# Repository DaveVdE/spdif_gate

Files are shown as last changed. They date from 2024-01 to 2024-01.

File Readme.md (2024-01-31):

# SPDIF Gate

Forked from [Elehobica's wonderful work](https://github.com/elehobica/pico_spdif_rx) on decoding the S/PDIF protocol on the RP2040's
PIO state machine, I used it to make this small program. I did however break the fork link so that I would not create a PR on the
upstream repo by mistake.

All credit is due to Elehobica's work. Most of the files in this repository come from upstream, I simply added the "spdif_gate" application
in the samples folder.

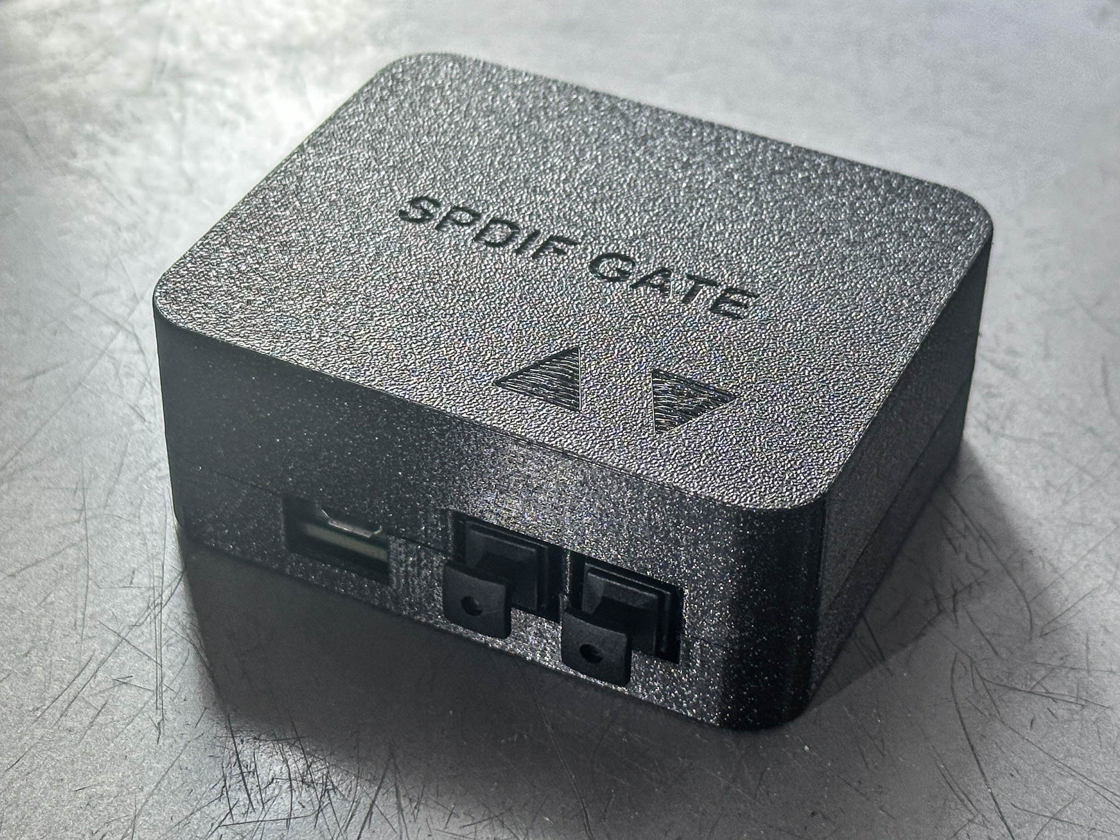
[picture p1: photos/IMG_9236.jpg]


This project started to solve a problem that was created by "Smart TVs" that don't go to sleep when you think they do. They keep humming 
in the background when the display is off, keeping a steady bit stream on their TOSLINK outputs. A family member uses a hairing aid and has 
the problem that a device he uses to convert the TV's optical audio into a bluetooth audio stream doesn't fully turn off when the TV is not 
in use, causing continuous audio cues as he moves around the house upon his hearing aid establishing link with the device near the TV.

I built a device with a custom PCB around a Raspberry Pi Pico, fitted with an optical receiver and transmitter with an AND gate in between 
(technically a quad NAND of which to gates are configured as an AND gate) so that the RP2040 can read the incoming S/PDIF signal and 
decide if real audio is transmitted or if it's just an empty stream with no audio, and turn the gate on and off accordingly 
(with a preset timeout of 3 minutes).

You can find some photos in the photos directory, the schematics and PCB files in the board directory and CAD models for the enclosure in the models directory.

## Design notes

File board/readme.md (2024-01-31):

This folder contains the schematic and PCB files from KiCad

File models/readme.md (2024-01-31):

This folder contains the CAD models used to create the enclosure.

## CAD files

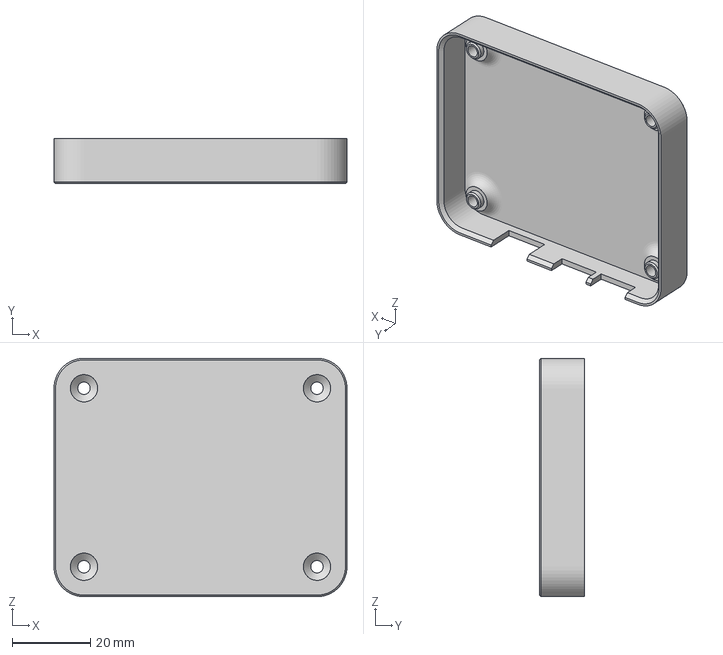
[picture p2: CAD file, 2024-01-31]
models/Bottom.3mf
75.0 x 11.6 x 61.1 mm

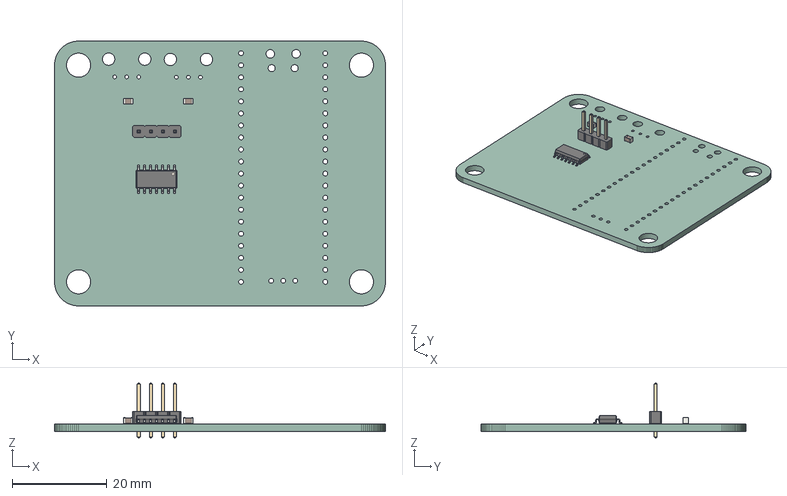
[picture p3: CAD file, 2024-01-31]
models/SPDIF gate.step
69.8 x 55.9 x 11.5 mm
_autosave-SPDIF gate PCB

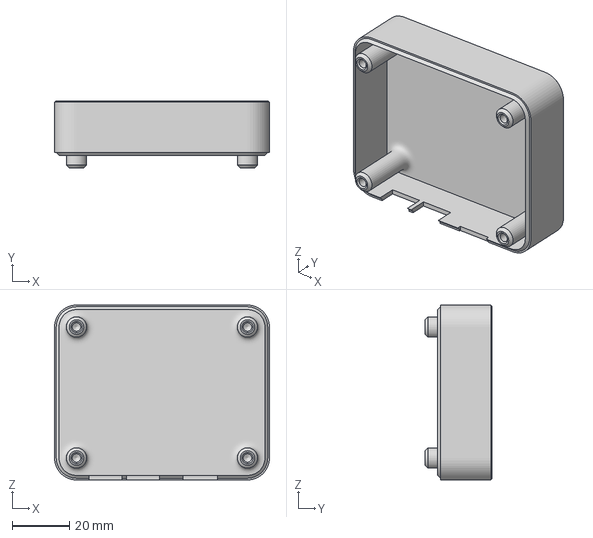
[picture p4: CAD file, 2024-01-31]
models/Top.3mf
75.0 x 23.4 x 61.1 mm

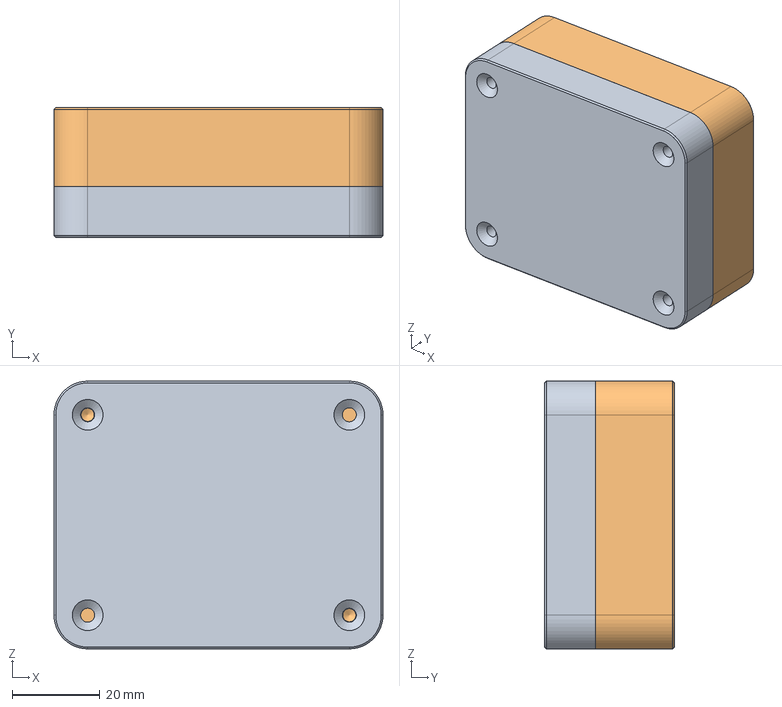
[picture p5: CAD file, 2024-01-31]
models/Enclosure v8.step
75.0 x 29.6 x 61.1 mm

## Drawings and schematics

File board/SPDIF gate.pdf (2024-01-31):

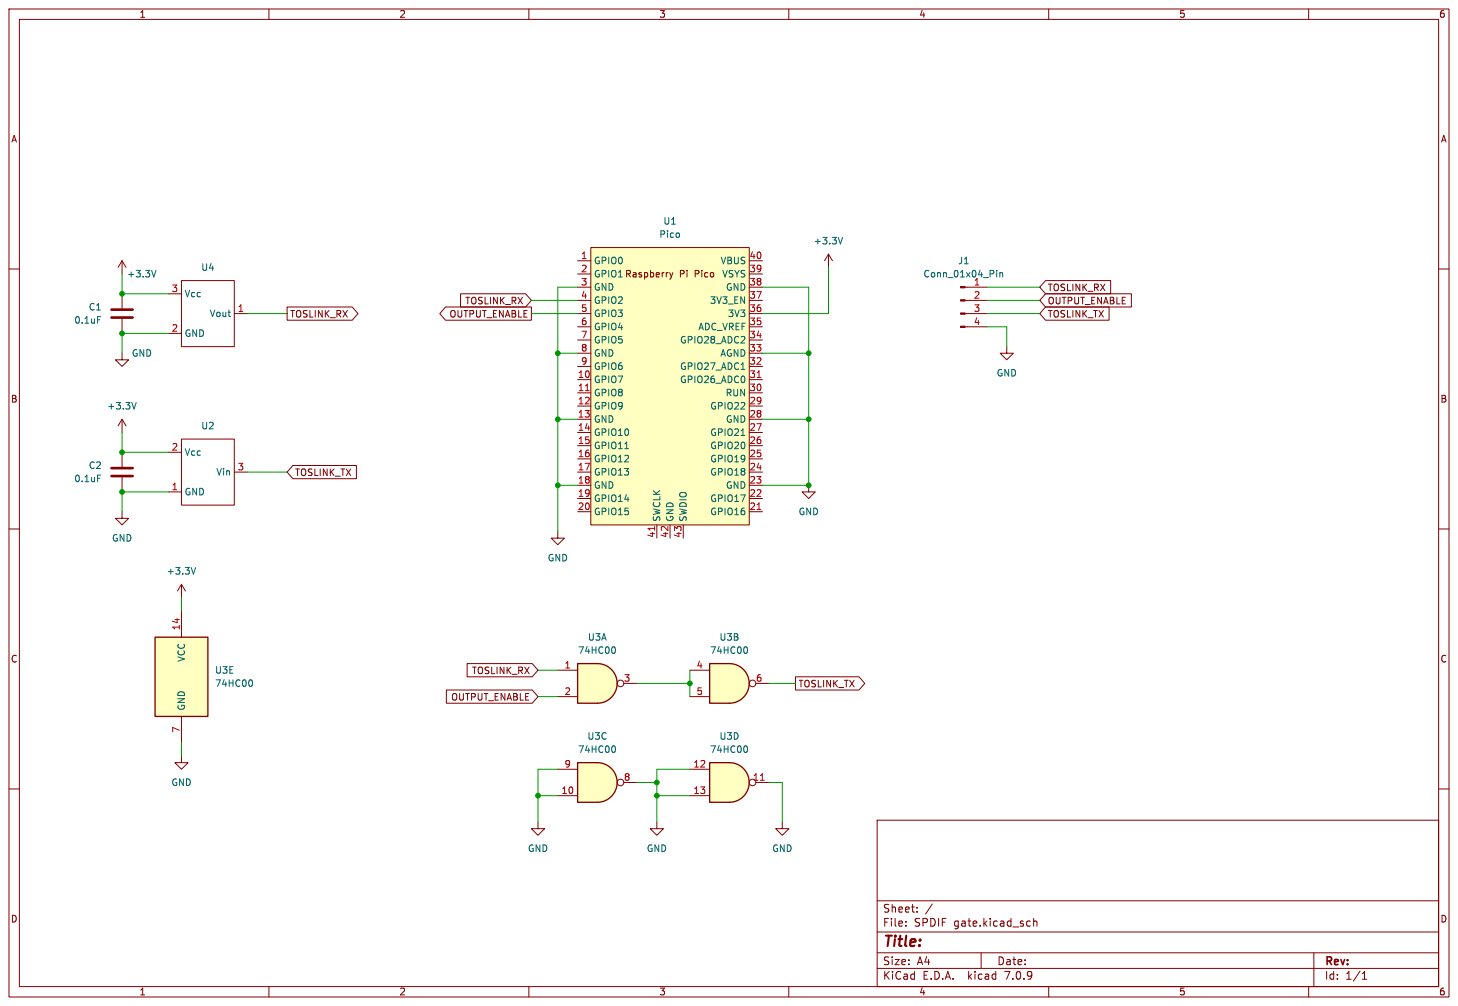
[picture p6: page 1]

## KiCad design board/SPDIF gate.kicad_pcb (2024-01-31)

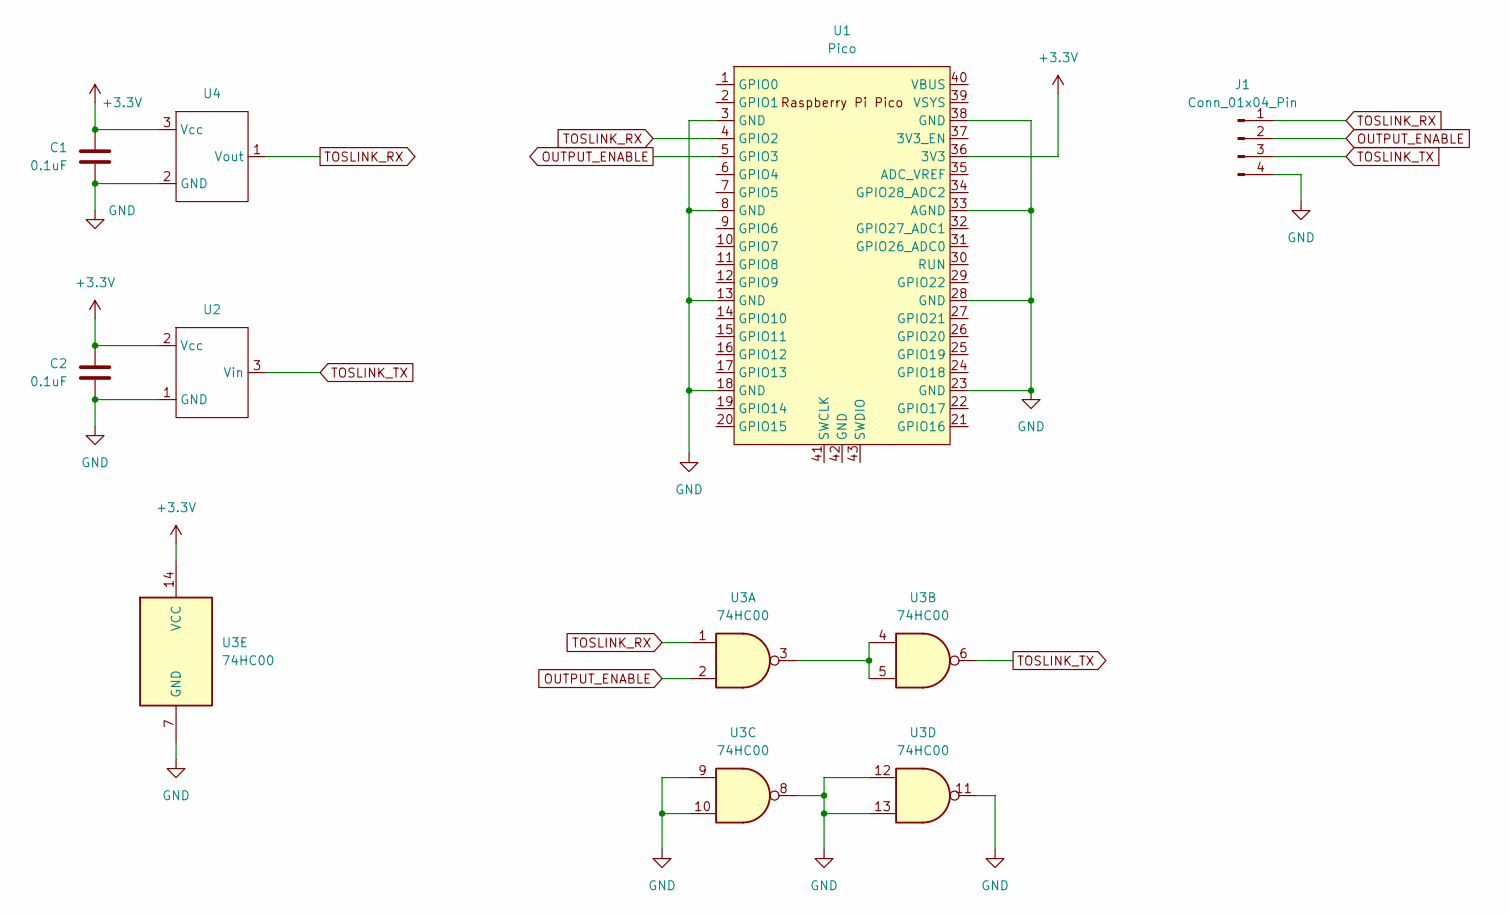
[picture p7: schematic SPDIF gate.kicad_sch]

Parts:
C1, C2: 0.1uF; C_0805_2012Metric
J1: Conn_01x04_Pin; PinHeader_1x04_P2.54mm_Vertical
U1: Pico; RPi_Pico_SMD_TH
U2: OTJ-1
U3: 74HC00; SOIC-14_3.9x8.7mm_P1.27mm
U4: ORJ-1

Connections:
+3.3V: C1.1, C2.1, U1.36 (3V3), U2.2 (Vcc), U3.14 (VCC), U4.3 (Vcc)
GND: C1.2, C2.2, J1.4, U1.3 (GND), U1.8 (GND), U1.13 (GND), U1.18 (GND), U1.23 (GND), U1.28 (GND), U1.33 (AGND), U1.38 (GND), U2.1 (GND), U3.7 (GND), U3.8, U3.9, U3.10, U3.11, U3.12, U3.13, U4.2 (GND)
unnamed: U3.3, U3.4, U3.5
OUTPUT_ENABLE: J1.2, U1.5 (GPIO3), U3.2
TOSLINK_RX: J1.1, U1.4 (GPIO2), U3.1, U4.1 (Vout)
TOSLINK_TX: J1.3, U2.3 (Vin), U3.6

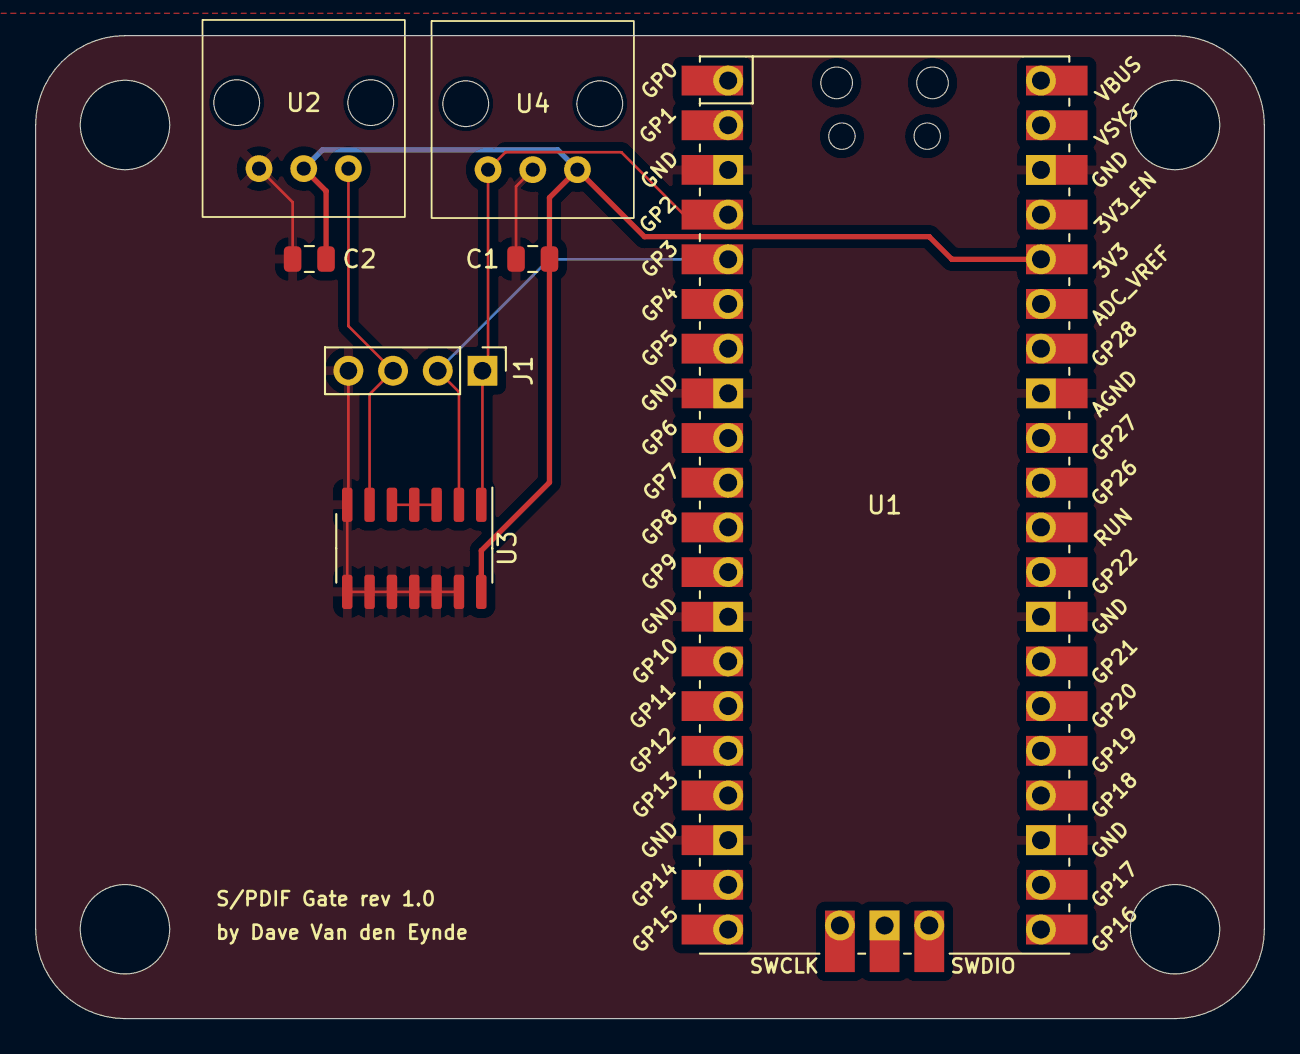
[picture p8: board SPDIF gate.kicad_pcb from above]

Board: 2 copper layers, 69.8 x 55.9 mm, 7 parts (0 on the bottom side), 6 nets.

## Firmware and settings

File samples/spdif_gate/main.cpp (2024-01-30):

/*------------------------------------------------------/
/ Copyright (c) 2023, Elehobica
/ Released under the BSD-2-Clause
/ refer to https://opensource.org/licenses/BSD-2-Clause
/------------------------------------------------------*/

#include <stdio.h>
#include "pico/stdlib.h"
#include "hardware/clocks.h"
#include "spdif_rx.h"

static constexpr uint8_t PIN_DCDC_PSM_CTRL = 23;
static constexpr uint8_t PIN_PICO_SPDIF_RX_DATA = 2;
static constexpr uint8_t PIN_PICO_SPDIF_ENABLE = 3;
static constexpr uint32_t TIMEOUT = 180;

volatile static bool stable_flg = false;
volatile static bool lost_stable_flg = false;

void measure_freqs(void) {
    uint f_pll_sys = frequency_count_khz(CLOCKS_FC0_SRC_VALUE_PLL_SYS_CLKSRC_PRIMARY);
    uint f_pll_usb = frequency_count_khz(CLOCKS_FC0_SRC_VALUE_PLL_USB_CLKSRC_PRIMARY);
    uint f_rosc = frequency_count_khz(CLOCKS_FC0_SRC_VALUE_ROSC_CLKSRC);
    uint f_clk_sys = frequency_count_khz(CLOCKS_FC0_SRC_VALUE_CLK_SYS);
    uint f_clk_peri = frequency_count_khz(CLOCKS_FC0_SRC_VALUE_CLK_PERI);
    uint f_clk_usb = frequency_count_khz(CLOCKS_FC0_SRC_VALUE_CLK_USB);
    uint f_clk_adc = frequency_count_khz(CLOCKS_FC0_SRC_VALUE_CLK_ADC);
    uint f_clk_rtc = frequency_count_khz(CLOCKS_FC0_SRC_VALUE_CLK_RTC);

    printf("pll_sys  = %dkHz\n", f_pll_sys);
    printf("pll_usb  = %dkHz\n", f_pll_usb);
    printf("rosc     = %dkHz\n", f_rosc);
    printf("clk_sys  = %dkHz\n", f_clk_sys);
    printf("clk_peri = %dkHz\n", f_clk_peri);
    printf("clk_usb  = %dkHz\n", f_clk_usb);
    printf("clk_adc  = %dkHz\n", f_clk_adc);
    printf("clk_rtc  = %dkHz\n", f_clk_rtc);

    // Can't measure clk_ref / xosc as it is the ref
}

void on_stable_func(spdif_rx_samp_freq_t samp_freq)
{
    // callback function should be returned as quick as possible
    stable_flg = true;
}

void on_lost_stable_func()
{
    // callback function should be returned as quick as possible
    lost_stable_flg = true;
}

void enable_output() {
    gpio_put(PIN_PICO_SPDIF_ENABLE, 1);
}

void disable_output() {
    gpio_put(PIN_PICO_SPDIF_ENABLE, 0);
}

void print_binary(uint32_t frame) {
    printf("0b");
    printf("%d", (frame >> 31) & 1);
    printf("%d", (frame >> 30) & 1);
    printf("%d", (frame >> 29) & 1);
    printf("%d", (frame >> 28) & 1);
    printf("%d", (frame >> 27) & 1);
    printf("%d", (frame >> 26) & 1);
    printf("%d", (frame >> 25) & 1);
    printf("%d", (frame >> 24) & 1);
    printf("%d", (frame >> 23) & 1);
    printf("%d", (frame >> 22) & 1);
    printf("%d", (frame >> 21) & 1);
    printf("%d", (frame >> 20) & 1);
    printf("%d", (frame >> 19) & 1);
    printf("%d", (frame >> 18) & 1);
    printf("%d", (frame >> 17) & 1);
    printf("%d", (frame >> 16) & 1);
    printf("%d", (frame >> 15) & 1);
    printf("%d", (frame >> 14) & 1);
    printf("%d", (frame >> 13) & 1);
    printf("%d", (frame >> 12) & 1);
    printf("%d", (frame >> 11) & 1);
    printf("%d", (frame >> 10) & 1);
    printf("%d", (frame >> 9) & 1);
    printf("%d", (frame >> 8) & 1);
    printf("%d", (frame >> 7) & 1);
    printf("%d", (frame >> 6) & 1);
    printf("%d", (frame >> 5) & 1);
    printf("%d", (frame >> 4) & 1);
    printf("%d", (frame >> 3) & 1);
    printf("%d", (frame >> 2) & 1);
    printf("%d", (frame >> 1) & 1);
    printf("%d", frame & 1);
    printf("\n");
}

int main()
{
    stdio_init_all();

    // DCDC PSM control
    // 0: PFM mode (best efficiency)
    // 1: PWM mode (improved ripple)
    gpio_init(PIN_DCDC_PSM_CTRL);
    gpio_set_dir(PIN_DCDC_PSM_CTRL, GPIO_OUT);
    gpio_put(PIN_DCDC_PSM_CTRL, 1); // PWM mode for less Audio noise

    // ENABLE control
    // 0: Output is not enabled
    // 1: Output is enabled
    gpio_init(PIN_PICO_SPDIF_ENABLE);
    gpio_set_dir(PIN_PICO_SPDIF_ENABLE, GPIO_OUT);
    disable_output();

    spdif_rx_config_t config = {
        .data_pin = PIN_PICO_SPDIF_RX_DATA,
        .pio_sm = 0,
        .dma_channel0 = 0,
        .dma_channel1 = 1,
        .alarm = 0,
        .flags = SPDIF_RX_FLAGS_ALL
    };

    spdif_rx_start(&config);
    spdif_rx_set_callback_on_stable(on_stable_func);
    spdif_rx_set_callback_on_lost_stable(on_lost_stable_func);

    printf("Starting...\n");

    int count = 0;
    int countdown = 0;

    while (true) {
        if (stable_flg) {
            stable_flg = false;
            printf("stable\n");
        }
        if (lost_stable_flg) {
            lost_stable_flg = false;
            printf("waiting\n");
        }
        if (count % 100 == 0) {            
            if (spdif_rx_get_state() == SPDIF_RX_STATE_STABLE) {
                //auto fifo_count = spdif_rx_get_fifo_count();
                //printf("Fifo count = %d\n", fifo_count);
                uint32_t* buffer;
                auto read = spdif_rx_read_fifo(&buffer, SPDIF_RX_FIFO_SIZE);
                //print_binary(buffer[0]);
                uint32_t first_frame = buffer[0] & 0x0ffffff0;
                if (first_frame & 0x0ffffff0) {
                    countdown = TIMEOUT;
                }
            }

            printf("Countdown: %d\n", countdown);

            if (countdown > 0) {
                printf("enabled\n");
                enable_output();
                --countdown;
            }
            else
            {
                printf("disabled\n");
                disable_output();
            }
        }
        
        tight_loop_contents();
        sleep_ms(10);
        count++;
    }

    return 0;
}
